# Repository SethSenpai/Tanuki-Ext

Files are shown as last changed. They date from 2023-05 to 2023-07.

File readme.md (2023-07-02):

# Tanuki-Ext OLED edition

The Tanuki-Ext is a redesign of the original [Tanuki Keyboard](https://github.com/SethSenpai/Tanuki). There were a few things about the original design that were preventing me from using it while coding and doing CAD. Most of all was the lack of dedicated arrow cluster. 

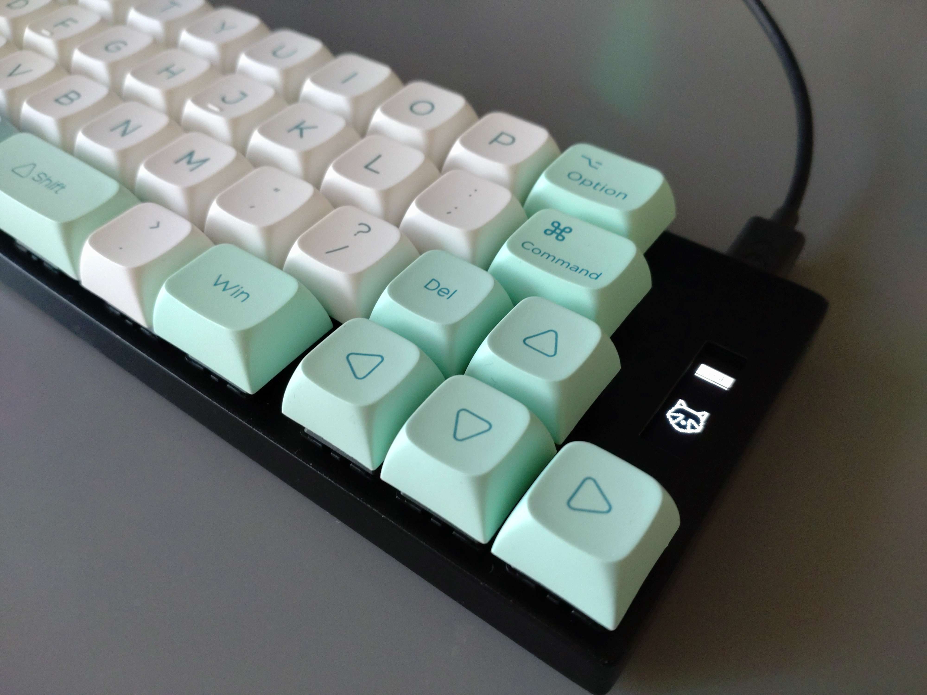
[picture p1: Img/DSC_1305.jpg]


The Tanuki-Ext fixes these issues and aims to create and even more open and accessible keyboard platform to experiment with by moving its firmware over to [CircuitPython](https://circuitpython.org/) and [KMKfw](http://kmkfw.io/). This allows you to access and modify your code without the need for extra programs, compilers or debuggers making it very approachable.

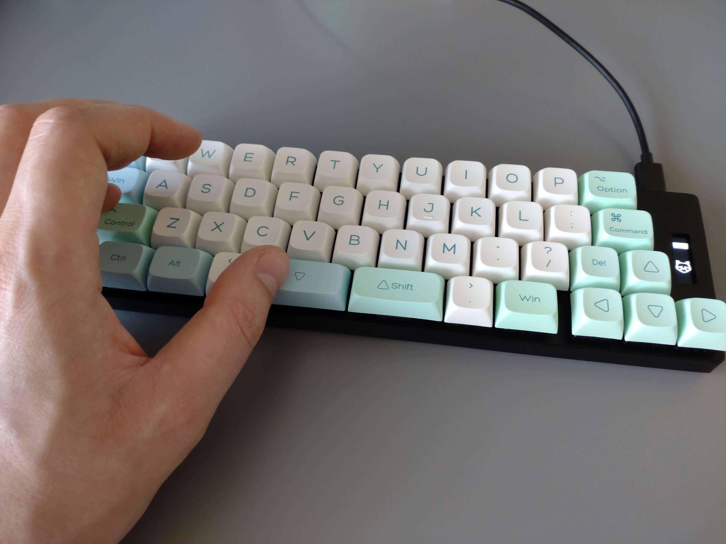
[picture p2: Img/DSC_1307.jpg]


## Layout
Like the original Tanuki keyboard the design has a split spacebar. Holding down the left spacebar brings you to the lower layer for numbers. Holding down the right spacebar brings you to the top layer for symbols. Never move your fingers from the homerow ever again!

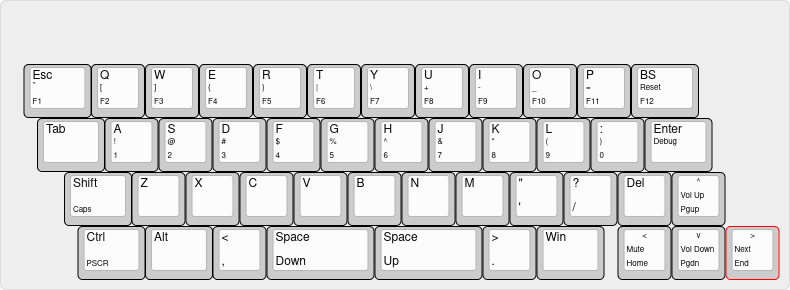
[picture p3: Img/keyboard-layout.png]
Layout overview


Both the firmware and design files of the Tanuki are distributed under GNU GPLv3 and are able to be used for commercial under [specific conditions](https://choosealicense.com/licenses/gpl-3.0/).

## Assembly

Assembling the device is quite straight forward. Create the casing from the files in the `Case` folder. Grab a hold of A `PCB` or handwire the keyboard using an [Raspberry Pi Pico](https://www.raspberrypi.com/products/raspberry-pi-pico/). Put on the backplate and close the whole thing up with 4 bolts. Check out the individual folders for further instructions. 

## Keycaps
Normally a full 104 key keycap set should have enough keys to cover the keyboard properly. Just to be sure I've made a list of the needed keycaps below.

| Size | Amount |
| ---- | --- |
| 2u | 2 |
| 1u | 37 |
| 1.25u | 8 |

I find the most comfortable keycap profile to be DSA or XDA keycaps since I don't need to worry about the keycap height being all over the place due to the uncommon layout of the Tanuki-Ext.

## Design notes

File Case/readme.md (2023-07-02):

# Case
This folder contains all the information you need to build the case for the Tanuki-Ext Oled. There are 2 different files. One for the case itself that will hold the switches and one for the backplate. Both files are available in `.stl` format for easy printing and `.step` format for future editing and or mods. 

As you may notice from the pictures below the entire case can be 3d printed and just about fits on my 3d printer which has a bed of 245mm x 245mm.

| | |
| --- | --- |
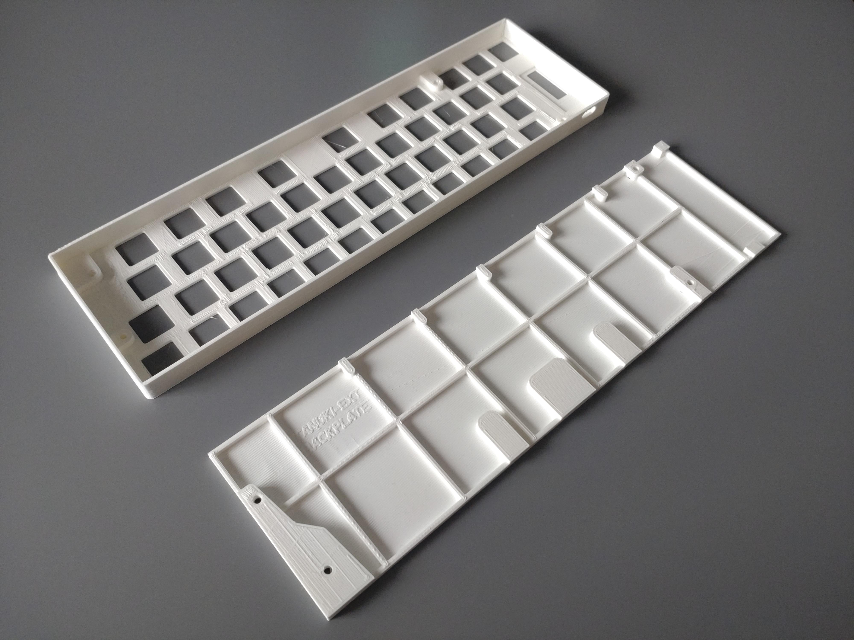
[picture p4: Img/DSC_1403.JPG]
Case Image
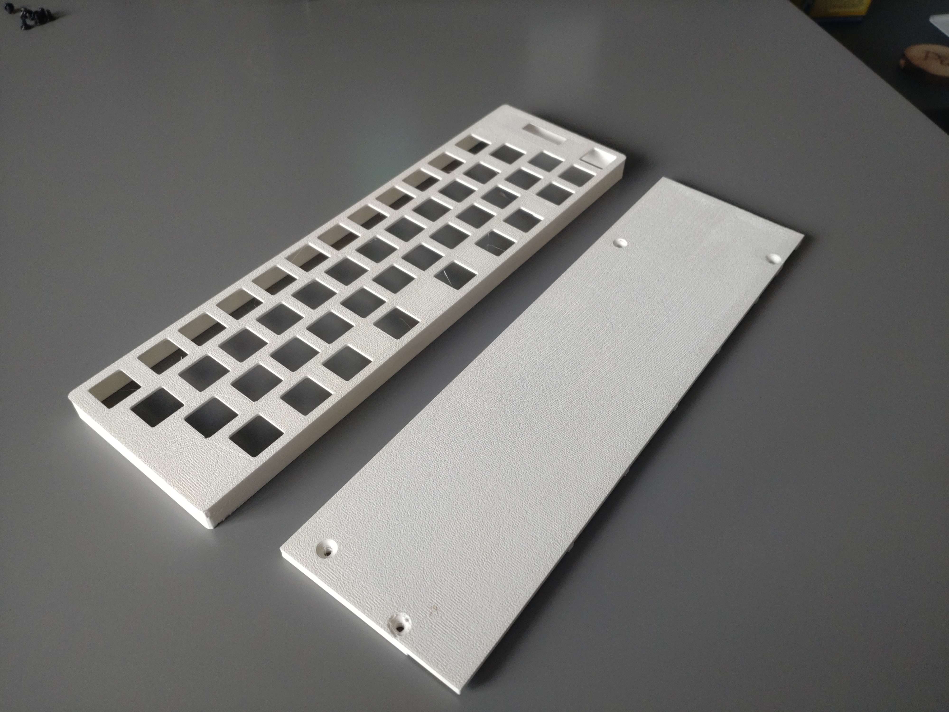
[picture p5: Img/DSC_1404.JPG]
Case Image 2
|||
|*The parts as printed* | *The underside of the printed parts* |

## 3D printer settings
I printed all my cases in PLA with a 50% infill. Make sure that your bed is leveled well as both parts are prone to warping and peeling.

It is recommended that you print both parts with their flat faces down on the bed. This means you don't have to use supports and prevents potential lamination issues.

The 2 parts go together with M3 10mm bolts. The mating holes in the case are sized so that a normal M3 bolt should go in and self tap. I've found this method to be quite reliable but feel free to use self tapping screws or threaded inserts.

## Required hardware

| Part | Amount |
| ---- | --- |
| M3 10mm Flathead bolt| 4 |
| Stickon rubber feet | 4 |
| 3D printing material for Backplate | 35g |
| 3D printing material for Case | 36g

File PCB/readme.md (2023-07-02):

# PCB

The PCB was designed in KiCAD 7.0. It is set up to allow you to modify it more easily. It has a couple of GPIO pins broken out as test pads. It also has footprints for WS2812 type LEDS in case you don't want to integrate an OLED screen.

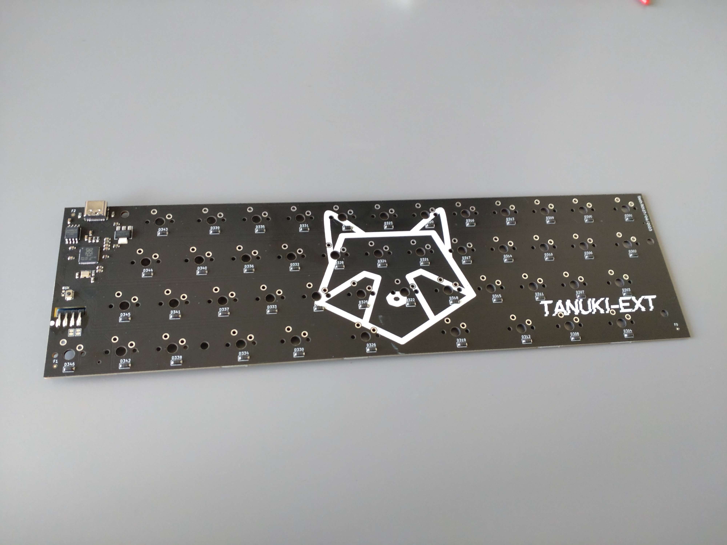
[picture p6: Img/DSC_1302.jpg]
Tanuki PCB


## Ordering PCB
The files in the _export folder contain both the gerbers, BOM and PNP files. These files are needed for a manufacturer to know how to make your pcb. What parts to place on it, and where to place those parts.

I ordered my prototype batch through JLC pcb and the export files are formatted as such. I decided to include them to make the process of making more PCB's as smooth as possible.

If you decide to have boards made at a different manufacturer you should check their knowledge base to make sure the files you give them adhere to their guidelines.

I would not recommend soldering this PCB by hand unless you know what you're doing. Some of the parts cannot be soldered with a soldering iron and require a hot air gun.
## Library
The folder contains a library for KiCAD 7.0 that holds the footprint for the 0.9 inch OLED module that this keyboard integrates. 
## Installing the OLED
The keyboard integrates a 0.91 inch OLED Display with a resolution of 128*32. It is driven by a SSD1306. See picture below.

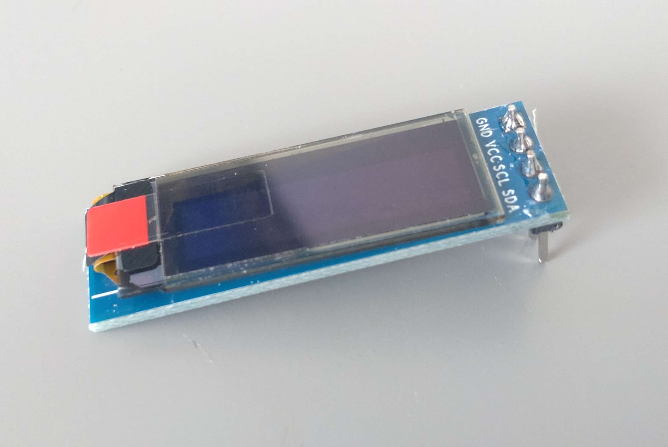
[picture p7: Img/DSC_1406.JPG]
picture of oled


I bought this OLED from a local electronic parts reseller. But you can find them pretty much everywhere. Like on this [AliExpress](https://www.aliexpress.com/item/32794209149.html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) listing. Just make sure the order of the pins is the same as the module shown above and that it's based on the SSD1306.

In order to install the OLED onto the PCB you need to bend its pins outward like shown in the image below.

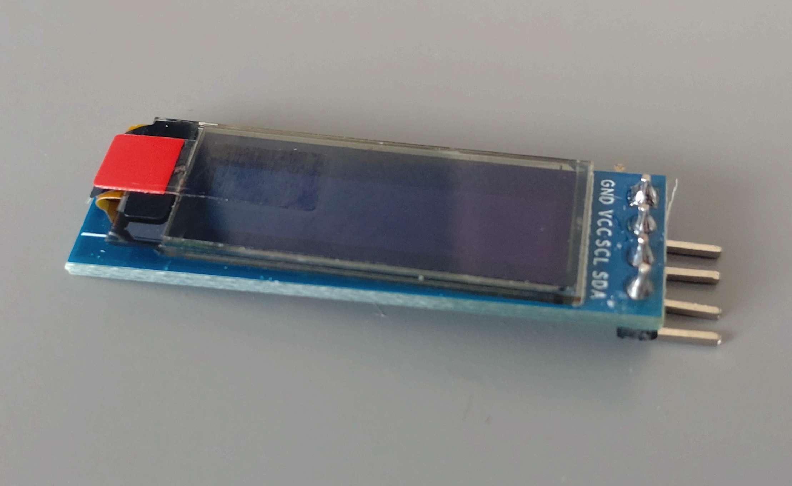
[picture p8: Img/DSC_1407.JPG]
OLED module with bend pins


The OLED then slots into the cutout on the board and can be soldered to the pads on the other side.

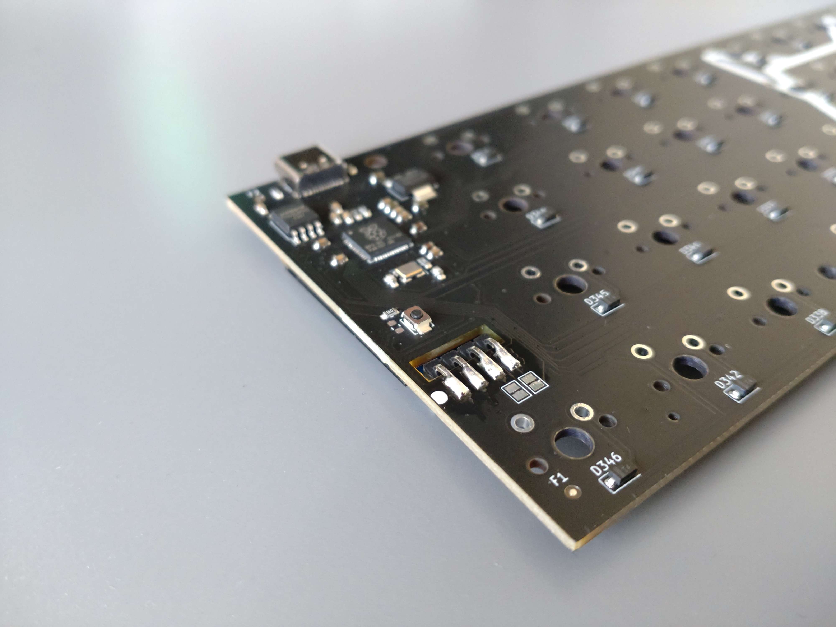
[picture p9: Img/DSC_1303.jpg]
OLED soldered to board


Make sure that the part where the OLED module lays on the board is covered in a piece of tape of some sort. This is to prevent potential shorts between the pads for the LEDS that are in that location and the backside of the OLED module.

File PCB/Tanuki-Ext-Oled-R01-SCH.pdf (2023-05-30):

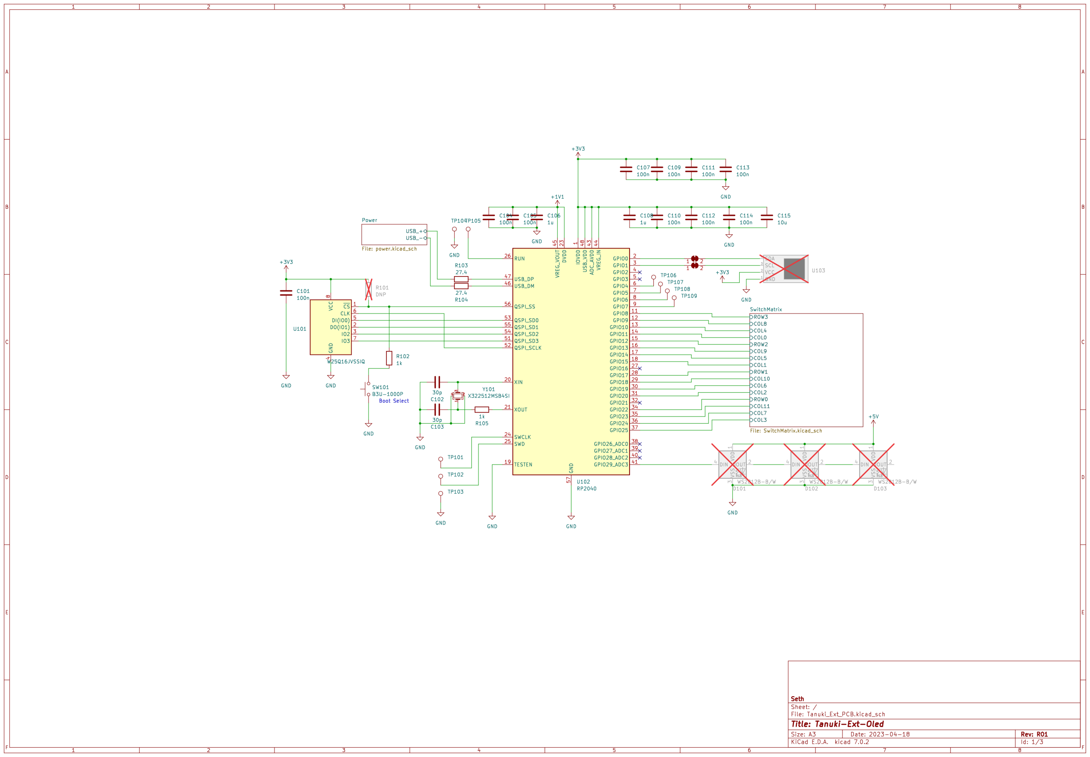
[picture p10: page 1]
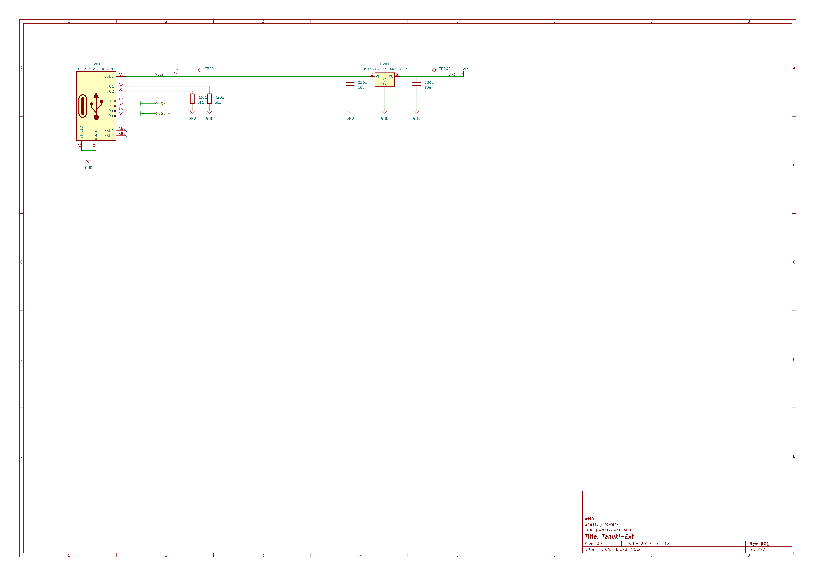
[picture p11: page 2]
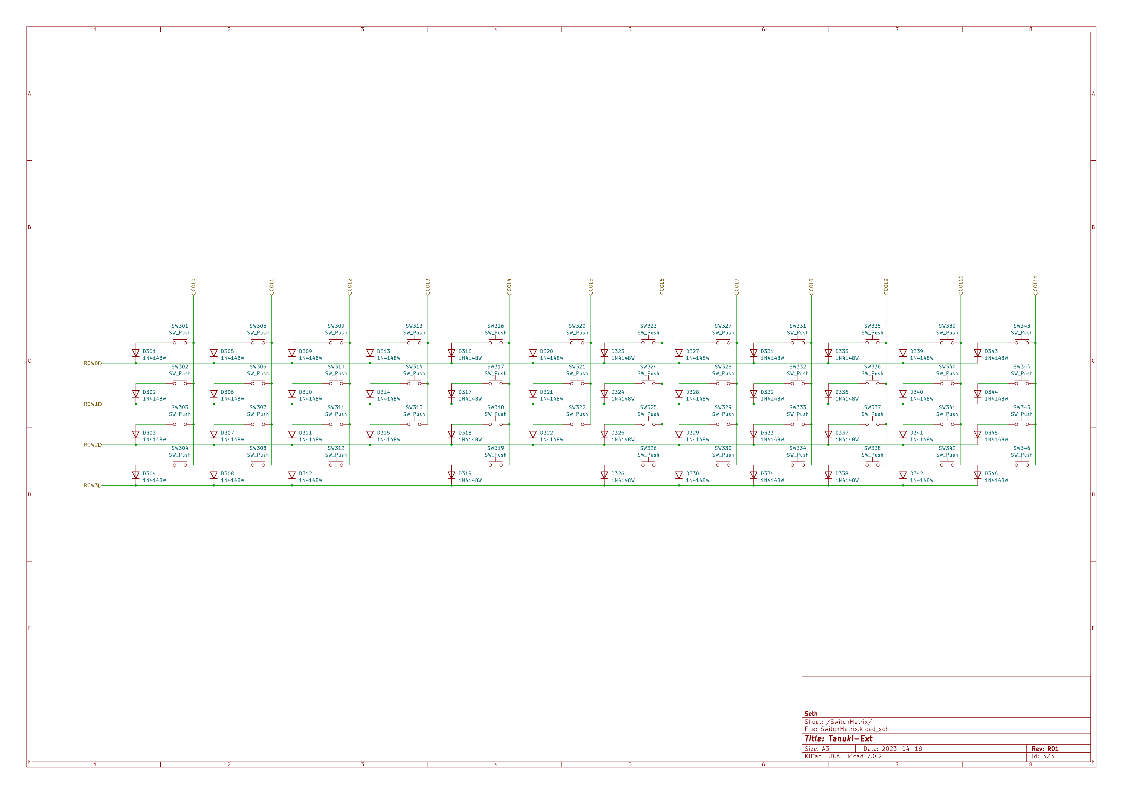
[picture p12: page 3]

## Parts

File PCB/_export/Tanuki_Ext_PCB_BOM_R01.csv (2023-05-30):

Comment | Designator | Footprint | LCSC
100n | C101,C104,C105,C107,C109,C110,C111,C112,C113,C114 | Capacitor_SMD:C_0603_1608Metric | C14663
30p | C102,C103 | Capacitor_SMD:C_0603_1608Metric | C113797
1u | C106,C108 | Capacitor_SMD:C_0603_1608Metric | C14664
10u | C115,C201,C202 | Capacitor_SMD:C_0603_1608Metric | C326057
1N4148W | D301,D302,D303,D304,D305,D306,D307,D308,D309,D310,D311,D312,D313,D314,D315,D316,D317,D318,D319,D320,D321,D322,D323,D324,D325,D326,D327,D328,D329,D330,D331,D332,D333,D334,D335,D336,D337,D338,D339,D340,D341,D342,D343,D344,D345,D346 | Diode_SMD:D_SOD-123F | C444720
U262-161N-4BVC11 | J201 | Connector_USB:USB_C_Receptacle_XKB_U262-16XN-4BVC11 | C319148
1k | R102,R105 | Resistor_SMD:R_0603_1608Metric | C22548
27.4 | R103,R104 | Resistor_SMD:R_0603_1608Metric | C5126244
5k1 | R201,R202 | Resistor_SMD:R_0603_1608Metric | C105580
B3U-1000P | SW101 | Button_Switch_SMD:SW_SPST_B3U-1000P | C231329
W25Q16JVSSIQ | U101 | Package_SO:SOIC-8_5.23x5.23mm_P1.27mm | C82317
RP2040 | U102 | Package_DFN_QFN:QFN-56-1EP_7x7mm_P0.4mm_EP3.2x3.2mm | C2040
LD1117AG-33-AA3-A-R | U201 | Package_TO_SOT_SMD:SOT-223-3_TabPin2 | C71121
X322512MSB4SI | Y101 | Crystal:Crystal_SMD_3225-4Pin_3.2x2.5mm | C9002

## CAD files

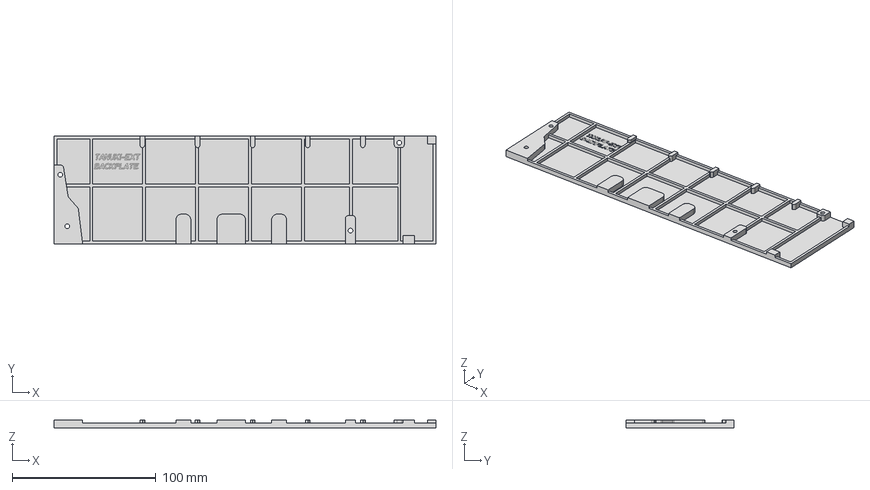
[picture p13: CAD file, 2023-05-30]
Case/Tanuki_Ext_Oled_Backplate.step
266.0 x 75.2 x 5.50 mm

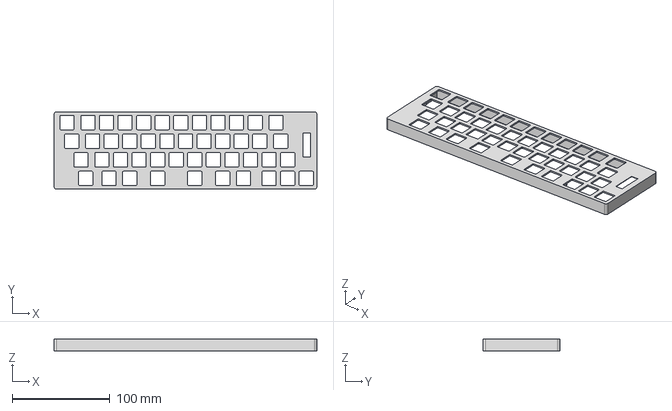
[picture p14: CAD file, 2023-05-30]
Case/Tanuki_Ext_Oled_Case.step
269.7 x 79.2 x 12.0 mm

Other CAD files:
Case/Tanuki_Ext_Oled_Backplate.stl
Case/Tanuki_Ext_Oled_Case.stl

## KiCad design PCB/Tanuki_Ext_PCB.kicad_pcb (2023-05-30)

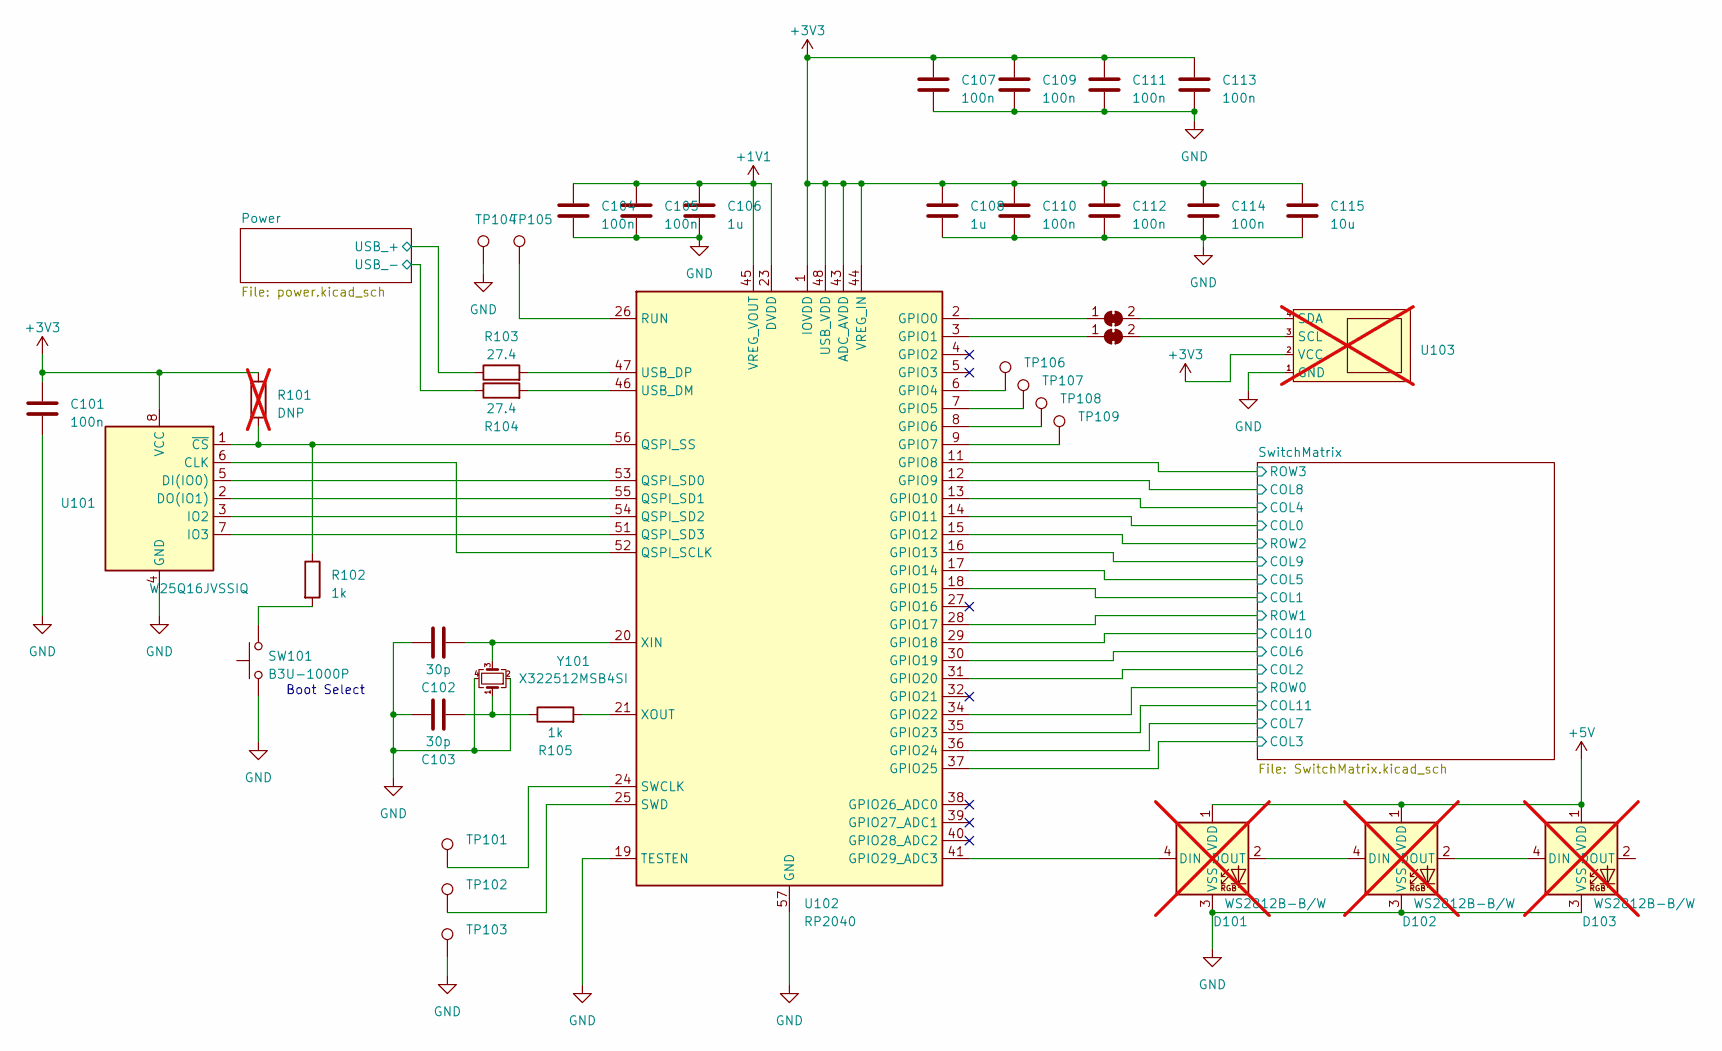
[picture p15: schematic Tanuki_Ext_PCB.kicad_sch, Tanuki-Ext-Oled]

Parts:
C101, C104, C105, C107, C109, C110, C111, C112, C113, C114: 100n; C_0603_1608Metric; LCSC Partnr. C14663
C102, C103: 30p; C_0603_1608Metric; LCSC Partnr. C113797
C106, C108: 1u; C_0603_1608Metric; LCSC Partnr. C14664
C115: 10u; C_0603_1608Metric; LCSC Partnr. C326057
D101, D102, D103: WS2812B-B/W; LED_WS2812B_PLCC4_5.0x5.0mm_P3.2mm; not fitted
JP101, JP102: SolderJumper_2_Bridged; SolderJumper-2_P1.3mm_Bridged_Pad1.0x1.5mm
R101: DNP; R_0603_1608Metric; not fitted
R102, R105: 1k; R_0603_1608Metric; LCSC Partnr. C22548
R103, R104: 27.4; R_0603_1608Metric; LCSC Partnr. C5126244
SW101: B3U-1000P; SW_SPST_B3U-1000P; LCSC Partnr. C231329
TP101, TP102, TP103, TP104, TP105, TP106, TP107, TP108, TP109: TestPoint; TestPoint_Pad_D1.0mm
U101: W25Q16JVSSIQ; SOIC-8_5.23x5.23mm_P1.27mm; LCSC Partnr. C82317
U102: RP2040; QFN-56-1EP_7x7mm_P0.4mm_EP3.2x3.2mm; LCSC Partnr. C2040
U103: Oled_0.91_i2c; not fitted
Y101: X322512MSB4SI; Crystal_SMD_3225-4Pin_3.2x2.5mm; LCSC Partnr. C9002

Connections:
+1V1: C104.1, C105.1, C106.1, U102.23 (DVDD), U102.45 (VREG_VOUT), U102.50 (DVDD)
/Power/USB_+: R103.1; also elsewhere on the board
/Power/USB_-: R104.1; also elsewhere on the board
/SwitchMatrix/COL0: U102.14 (GPIO11); also elsewhere on the board
/SwitchMatrix/COL1: U102.18 (GPIO15); also elsewhere on the board
/SwitchMatrix/COL2: U102.31 (GPIO20); also elsewhere on the board
/SwitchMatrix/COL3: U102.37 (GPIO25); also elsewhere on the board
/SwitchMatrix/COL4: U102.13 (GPIO10); also elsewhere on the board
/SwitchMatrix/COL5: U102.17 (GPIO14); also elsewhere on the board
/SwitchMatrix/COL6: U102.30 (GPIO19); also elsewhere on the board
/SwitchMatrix/COL7: U102.36 (GPIO24); also elsewhere on the board
/SwitchMatrix/COL8: U102.12 (GPIO9); also elsewhere on the board
/SwitchMatrix/COL9: U102.16 (GPIO13); also elsewhere on the board
/SwitchMatrix/COL10: U102.29 (GPIO18); also elsewhere on the board
/SwitchMatrix/COL11: U102.35 (GPIO23); also elsewhere on the board
/SwitchMatrix/ROW0: U102.34 (GPIO22); also elsewhere on the board
/SwitchMatrix/ROW1: U102.28 (GPIO17); also elsewhere on the board
/SwitchMatrix/ROW2: U102.15 (GPIO12); also elsewhere on the board
/SwitchMatrix/ROW3: U102.11 (GPIO8); also elsewhere on the board
GND: C101.2, C102.2, C103.2, C104.2, C105.2, C106.2, C107.2, C108.2, C109.2, C110.2, C111.2, C112.2, C113.2, C114.2, C115.2, D101.3 (VSS), D102.3 (VSS), D103.3 (VSS), SW101.1, TP103.1, TP104.1, U101.4 (GND), U102.19 (TESTEN), U102.57 (GND), U103.1 (GND), Y101.2, Y101.4; also elsewhere on the board
unnamed: C103.1, R105.1, Y101.1
unnamed: D101.4 (DIN), U102.41 (GPIO29_ADC3)
unnamed: D101.2 (DOUT), D102.4 (DIN)
unnamed: D102.2 (DOUT), D103.4 (DIN)
unnamed: JP101.1 (A), U102.2 (GPIO0)
unnamed: JP101.2 (B), U103.4 (SDA)
unnamed: JP102.1 (A), U102.3 (GPIO1)
unnamed: JP102.2 (B), U103.3 (SCL)
unnamed: R102.2, SW101.2
unnamed: U101.6 (CLK), U102.52 (QSPI_SCLK)
unnamed: U101.5 (DI(IO0)), U102.53 (QSPI_SD0)
unnamed: U101.2 (DO(IO1)), U102.55 (QSPI_SD1)
unnamed: U101.3 (IO2), U102.54 (QSPI_SD2)
unnamed: U101.7 (IO3), U102.51 (QSPI_SD3)
unnamed: R101.2, R102.1, U101.1 (~CS), U102.56 (QSPI_SS)
unnamed: TP106.1, U102.6 (GPIO4)
unnamed: TP107.1, U102.7 (GPIO5)
unnamed: TP108.1, U102.8 (GPIO6)
unnamed: TP105.1, U102.26 (RUN)
unnamed: TP101.1, U102.24 (SWCLK)
unnamed: TP102.1, U102.25 (SWD)
unnamed: R104.2, U102.46 (USB_DM)
unnamed: R103.2, U102.47 (USB_DP)
unnamed: C102.1, U102.20 (XIN), Y101.3
unnamed: R105.2, U102.21 (XOUT)

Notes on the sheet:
Boot Select

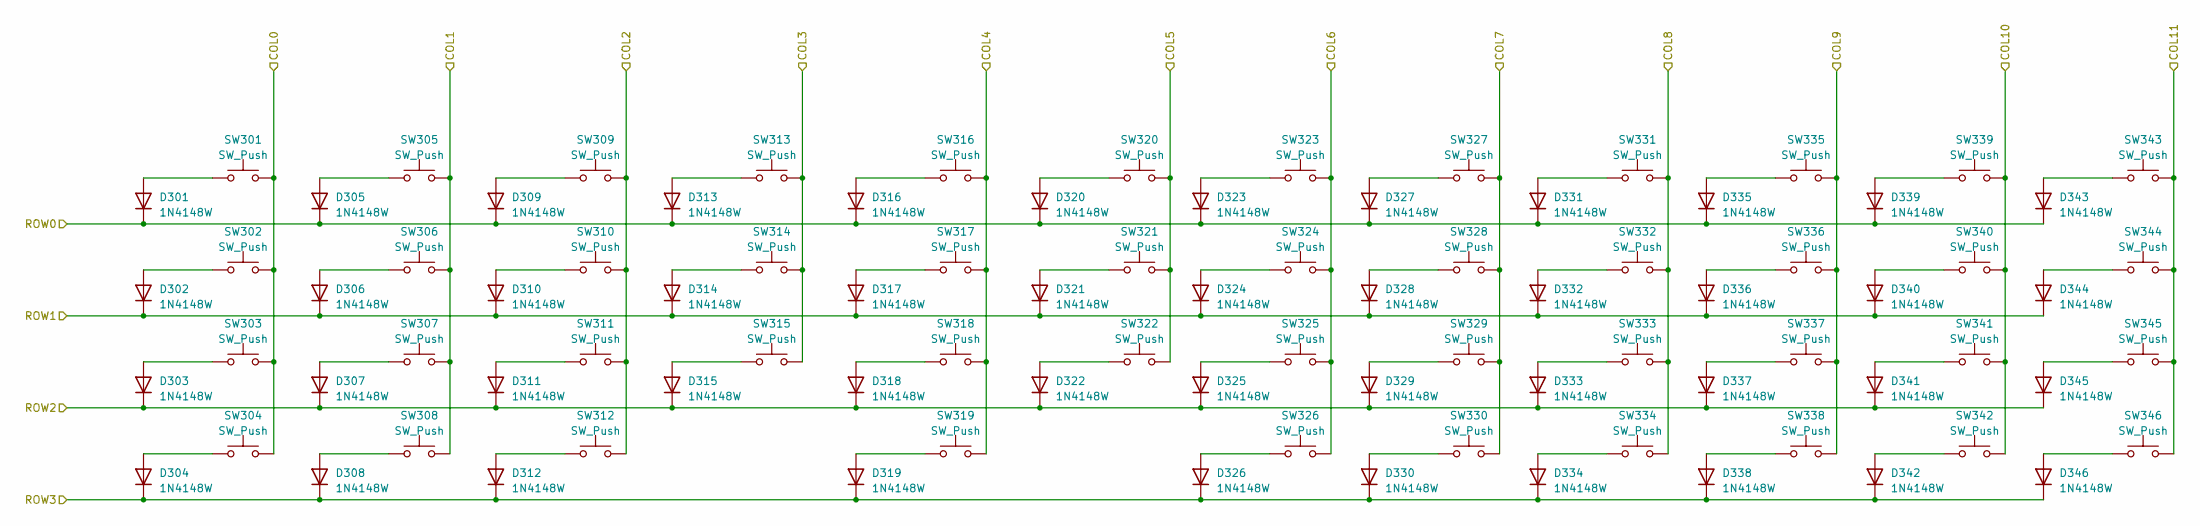
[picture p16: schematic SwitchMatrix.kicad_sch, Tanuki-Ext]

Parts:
D301, D302, D303, D304, D305, D306, D307, D308, D309, D310, D311, D312, D313, D314, D315, D316, D317, D318, D319, D320, D321, D322, D323, D324, D325, D326, D327, D328, D329, D330, D331, D332, D333, D334, D335, D336, D337, D338, D339, D340, D341, D342, D343, D344, D345, D346: 1N4148W; D_SOD-123F; LCSC Partnr. C444720
SW301, SW302, SW303, SW304, SW308, SW334, SW343, SW344: SW_Push; SW_Cherry_MX_PCB_1.25u
SW305, SW306, SW307, SW309, SW310, SW311, SW312, SW313, SW314, SW315, SW316, SW317, SW318, SW320, SW321, SW322, SW323, SW324, SW325, SW327, SW328, SW329, SW330, SW331, SW332, SW333, SW335, SW336, SW337, SW338, SW339, SW340, SW341, SW342, SW345, SW346: SW_Push; SW_Cherry_MX_PCB_1.00u
SW319, SW326: SW_Push; SW_Cherry_MX_PCB_2.00u

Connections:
/SwitchMatrix/COL0: SW301.2, SW302.2, SW303.2, SW304.2; also elsewhere on the board
/SwitchMatrix/COL1: SW305.2, SW306.2, SW307.2, SW308.2; also elsewhere on the board
/SwitchMatrix/COL2: SW309.2, SW310.2, SW311.2, SW312.2; also elsewhere on the board
/SwitchMatrix/COL3: SW313.2, SW314.2, SW315.2; also elsewhere on the board
/SwitchMatrix/COL4: SW316.2, SW317.2, SW318.2, SW319.2; also elsewhere on the board
/SwitchMatrix/COL5: SW320.2, SW321.2, SW322.2; also elsewhere on the board
/SwitchMatrix/COL6: SW323.2, SW324.2, SW325.2, SW326.2; also elsewhere on the board
/SwitchMatrix/COL7: SW327.2, SW328.2, SW329.2, SW330.2; also elsewhere on the board
/SwitchMatrix/COL8: SW331.2, SW332.2, SW333.2, SW334.2; also elsewhere on the board
/SwitchMatrix/COL9: SW335.2, SW336.2, SW337.2, SW338.2; also elsewhere on the board
/SwitchMatrix/COL10: SW339.2, SW340.2, SW341.2, SW342.2; also elsewhere on the board
/SwitchMatrix/COL11: SW343.2, SW344.2, SW345.2, SW346.2; also elsewhere on the board
/SwitchMatrix/ROW0: D301.1 (K), D305.1 (K), D309.1 (K), D313.1 (K), D316.1 (K), D320.1 (K), D323.1 (K), D327.1 (K), D331.1 (K), D335.1 (K), D339.1 (K), D343.1 (K); also elsewhere on the board
/SwitchMatrix/ROW1: D302.1 (K), D306.1 (K), D310.1 (K), D314.1 (K), D317.1 (K), D321.1 (K), D324.1 (K), D328.1 (K), D332.1 (K), D336.1 (K), D340.1 (K), D344.1 (K); also elsewhere on the board
/SwitchMatrix/ROW2: D303.1 (K), D307.1 (K), D311.1 (K), D315.1 (K), D318.1 (K), D322.1 (K), D325.1 (K), D329.1 (K), D333.1 (K), D337.1 (K), D341.1 (K), D345.1 (K); also elsewhere on the board
/SwitchMatrix/ROW3: D304.1 (K), D308.1 (K), D312.1 (K), D319.1 (K), D326.1 (K), D330.1 (K), D334.1 (K), D338.1 (K), D342.1 (K), D346.1 (K); also elsewhere on the board
unnamed: D301.2 (A), SW301.1
unnamed: D302.2 (A), SW302.1
unnamed: D303.2 (A), SW303.1
unnamed: D304.2 (A), SW304.1
unnamed: D305.2 (A), SW305.1
unnamed: D306.2 (A), SW306.1
unnamed: D307.2 (A), SW307.1
unnamed: D308.2 (A), SW308.1
unnamed: D309.2 (A), SW309.1
unnamed: D310.2 (A), SW310.1
unnamed: D311.2 (A), SW311.1
unnamed: D312.2 (A), SW312.1
unnamed: D313.2 (A), SW313.1
unnamed: D314.2 (A), SW314.1
unnamed: D315.2 (A), SW315.1
unnamed: D316.2 (A), SW316.1
unnamed: D317.2 (A), SW317.1
unnamed: D318.2 (A), SW318.1
unnamed: D319.2 (A), SW319.1
unnamed: D320.2 (A), SW320.1
unnamed: D321.2 (A), SW321.1
unnamed: D322.2 (A), SW322.1
unnamed: D323.2 (A), SW323.1
unnamed: D324.2 (A), SW324.1
unnamed: D325.2 (A), SW325.1
unnamed: D326.2 (A), SW326.1
unnamed: D327.2 (A), SW327.1
unnamed: D328.2 (A), SW328.1
unnamed: D329.2 (A), SW329.1
unnamed: D330.2 (A), SW330.1
unnamed: D331.2 (A), SW331.1
unnamed: D332.2 (A), SW332.1
unnamed: D333.2 (A), SW333.1
unnamed: D334.2 (A), SW334.1
unnamed: D335.2 (A), SW335.1
unnamed: D336.2 (A), SW336.1
unnamed: D337.2 (A), SW337.1
unnamed: D338.2 (A), SW338.1
unnamed: D339.2 (A), SW339.1
unnamed: D340.2 (A), SW340.1
unnamed: D341.2 (A), SW341.1
unnamed: D342.2 (A), SW342.1
unnamed: D343.2 (A), SW343.1
unnamed: D344.2 (A), SW344.1
unnamed: D345.2 (A), SW345.1
unnamed: D346.2 (A), SW346.1

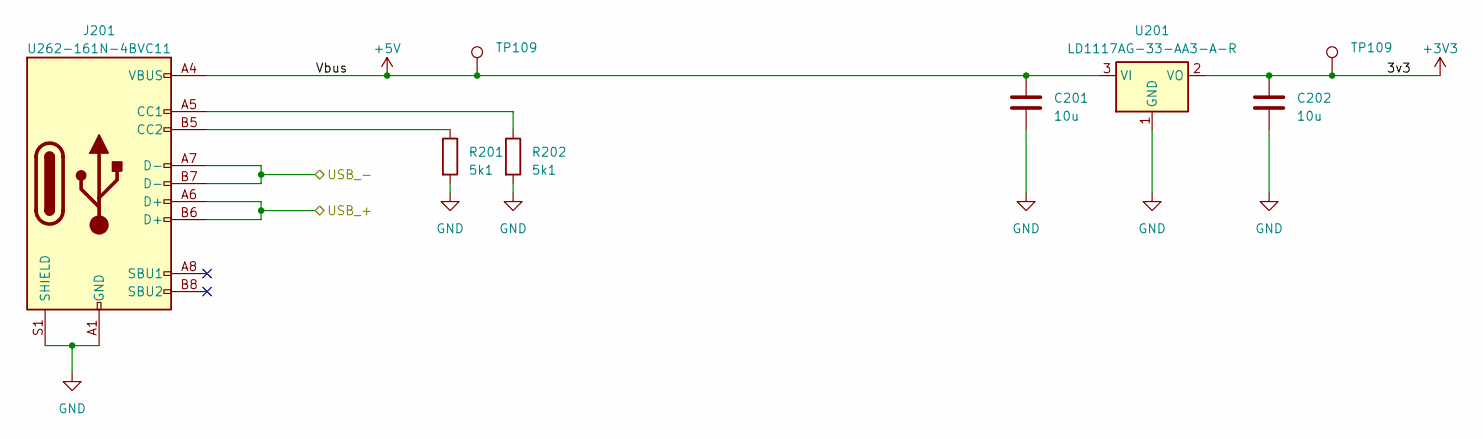
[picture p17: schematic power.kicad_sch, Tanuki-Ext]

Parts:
C201, C202: 10u; C_0603_1608Metric; LCSC Partnr. C326057
J201: U262-161N-4BVC11; USB_C_Receptacle_XKB_U262-16XN-4BVC11; LCSC Partnr. C319148
R201, R202: 5k1; R_0603_1608Metric; LCSC Partnr. C105580
TP109: TestPoint; TestPoint_Pad_D1.0mm
U201: LD1117AG-33-AA3-A-R; SOT-223-3_TabPin2; LCSC Partnr. C71121

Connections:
/Power/USB_+: J201.A6 (D+), J201.B6 (D+); also elsewhere on the board
/Power/USB_-: J201.A7 (D-), J201.B7 (D-); also elsewhere on the board
GND: C201.2, C202.2, J201.A1 (GND), J201.A12 (GND), J201.B1 (GND), J201.B12 (GND), J201.S1 (SHIELD), R201.2, R202.2, U201.1 (GND); also elsewhere on the board
unnamed: J201.A5 (CC1), R202.1
unnamed: J201.B5 (CC2), R201.1

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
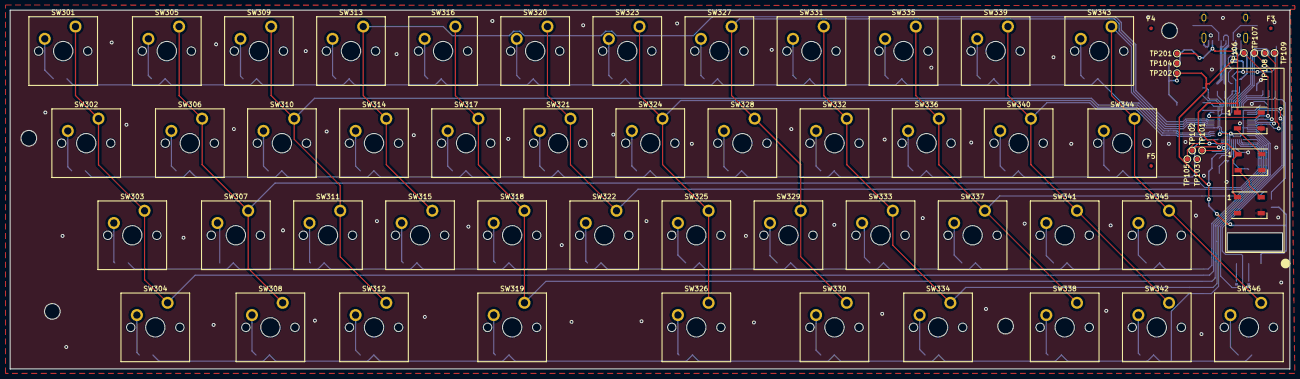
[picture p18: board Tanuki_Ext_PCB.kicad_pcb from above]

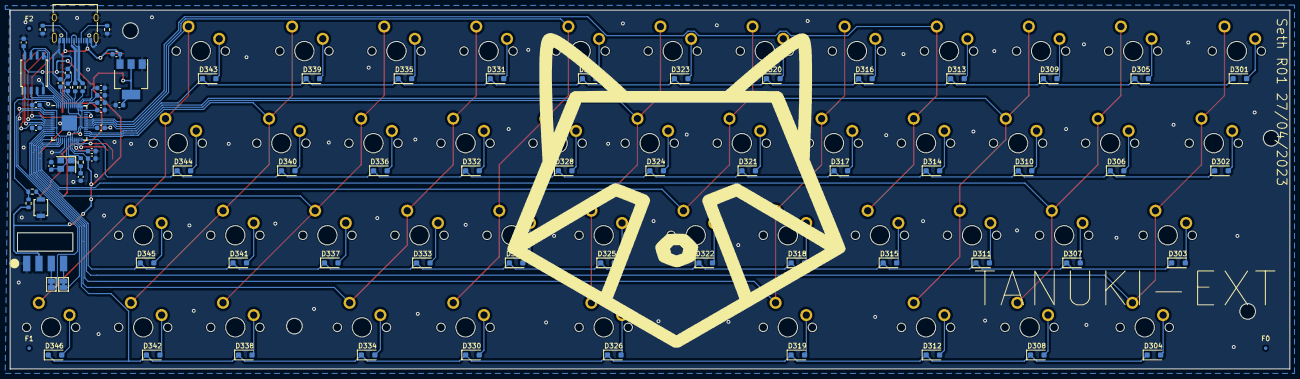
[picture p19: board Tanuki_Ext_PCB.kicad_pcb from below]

Board: 2 copper layers, 264.7 x 74.2 mm, 145 parts (81 on the bottom side), 96 nets.

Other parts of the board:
F0, F1, F2, F3, F4, F5: Fiducial_0.75mm_Mask1.5mm
TP201, TP202: TestPoint; TestPoint_Pad_D1.0mm

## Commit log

2023-05-30 inital commit
    [SwitchMatrix.kicad_sch, Tanuki_Ext_Oled_Backplate.step, Tanuki_Ext_Oled_Backplate.stl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]
2023-07-01 added readme for case
2023-07-01 readme for case
